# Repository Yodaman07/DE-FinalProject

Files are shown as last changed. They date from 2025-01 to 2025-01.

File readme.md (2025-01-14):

# Digital Electronics Final Project
### 3D Space Controller

## What does it do

The 3D Space Controller is a device that allows for traversal in 3D environments. You plug it into your computer and turn it on, and through hand gestures the device should allow for the rotation of a 3D landscape (currently only working in Blender) 

## How does it work

Pi: As you move your hand, the camera picks up what is happening and the pi (using mediapipe) processes the coordinates of your pointer finger, and puts it into `pi/data.json`. On a different thread, the pi is connected to the same wifi network as the arduino which enables it to send the data from that file to your "thing" on arduino cloud.

Arduino: The arduino then picks up that data and will move your mouse to those locations on your computer. **NOTE** It is essential to use an HID enabled arduino

## BOM

For the version of the device that I built, here were the materials that I used:

- Microsoft-Life-Cam-3000
- Raspberry Pi 4b
- Raspberry Pi Power supply
- Raspberry Pi 4b Case
- Arduino Nano ESP32
- USB-C to USB-C cable
- Front and Back plates printed in PLA (CAD located in `CAD/`) 
- Duct Tape and Foam from the box of the Arduino (The CAD had some issues which meant I had to be creative with fitting everything together)

## How to use yourself

On the pi inside of a venv (set up with `python -m venv env`, enter with `source env/bin/activate`, and leave with `deactivate`):

- Run `pip install -r requirements.txt` to install the necessary requirements
- Add a `.env` file to the `pi/` directory filled with your Arduino `DEVICE_ID` and `SECRET_KEY`
- Run `main.py`

Arduino Setup:

## Known Issues

It lags really badly - and the camera I'm using does not react well to really bright light

The CAD is kind of broken (things don't fit without some creative solutions) and doesn't needs to be adjusted more closely. The CAD models I ended up using were my prototype files that I printed once. 

## Cut Content (may be added in future versions)

Changing keystroke settings with an lcd
- I started to write code for it in `testing/lcd_controller` but didn't have time to implement it
- Additionally, I wanted to add a functionality with a joystick for manual control but I never got to experimenting with it

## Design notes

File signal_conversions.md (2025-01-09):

### Signal Conversions

After parsing the hand movements the raspberry pi needs to send them to the arduino before it can be sent to the computer. In doing this, the pi will send numbers associated with various keys and mouse commands that will be parsed/interpreted by the arduino then executed on your machine. Here are the key codes.

| Value (String) | Command |
|---|---|
| 10 | middleMouseDown |
| 11 | middleMouseUp |
| 20 | leftMouseDown |
| 21 | leftMouseUp |
| 30 | rightMouseDown |
| 31 | rightMouseUp |
| 123456788 | move_start |
| Numbers sent while movement is active | move(x,y) ; They are received as alternating x-y pairs |
| 123456789 | move_end |
| 404 | stop mouse control |

I should probably use a regex to read x/y coords, but I don't have too much time to implement it. I will probably come back and optimize this later.

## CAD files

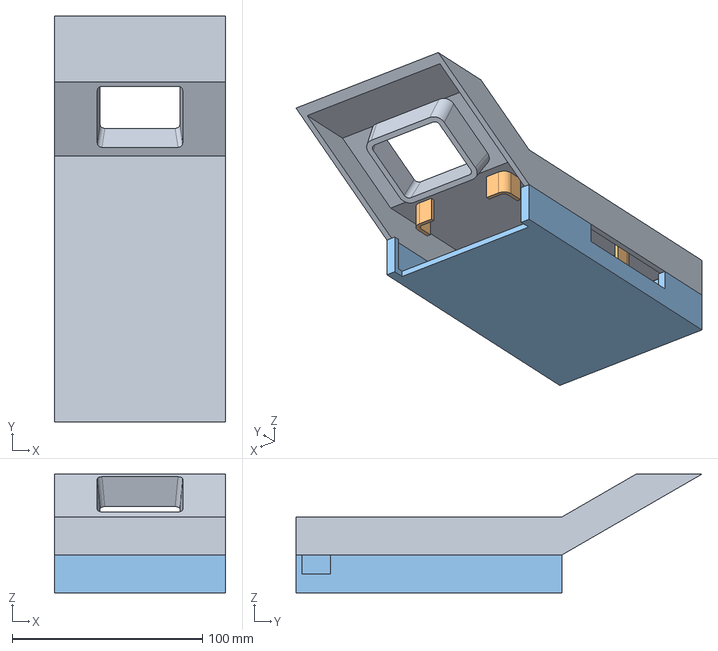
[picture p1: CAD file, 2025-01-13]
CAD/Case.step
90.0 x 213.6 x 62.5 mm
Front Plate
Back Plate

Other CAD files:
CAD/Case.f3z

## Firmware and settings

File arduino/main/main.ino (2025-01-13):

#include "thingProperties.h"
#include "USB.h"
#include "USBHIDMouse.h"



USBHIDMouse Mouse;


bool movementActive = false;
void setup() {
  // Initialize serial and wait for port to open:
  Serial.begin(9600);
  // This delay gives the chance to wait for a Serial Monitor without blocking if none is found
  delay(1500);

  // Defined in thingProperties.h
  initProperties();

  // Connect to Arduino IoT Cloud
  ArduinoCloud.begin(ArduinoIoTPreferredConnection);

  /*
     The following function allows you to obtain more information
     related to the state of network and IoT Cloud connection and errors
     the higher number the more granular information you’ll get.
     The default is 0 (only errors).
     Maximum is 4
 */
  setDebugMessageLevel(2);
  ArduinoCloud.printDebugInfo();

  USB.begin();
  Mouse.begin();
}

void loop() {
  ArduinoCloud.update();
  // Your code here

  // put your main code here, to run repeatedly:
  if ((mouseX != -1) && (mouseY !=-1) ){
      // Serial.print(mouseX);
      // Serial.print(" and ");
      // Serial.print(mouseY);
      // Serial.print(" ; ");
      // Serial.println(movementActive);
      Mouse.move(mouseX, mouseY);
      movementActive = true;
  }else{movementActive = false;}

  if (!movementActive){scanForOpperations(mouseState);} //Listening for other mouse signals if movement isn't active

}

void scanForOpperations(int data){
  switch (data){
      case 10:
        Mouse.press(MOUSE_MIDDLE);
        break;
      case 11:
        Mouse.release(MOUSE_MIDDLE);
        break;
      case 20:
        Mouse.press(MOUSE_LEFT);
        break;
      case 21:
        Mouse.release(MOUSE_LEFT);
        break;
      case 30:
        Mouse.press(MOUSE_RIGHT);
        break;
      case 31:
        Mouse.release(MOUSE_RIGHT);
        break;
      case 404:
        Mouse.end();
        break;
    }
}

/*
  Since MouseX is READ_WRITE variable, onMouseXChange() is
  executed every time a new value is received from IoT Cloud.
*/
void onMouseXChange()  {
  // Add your code here to act upon MouseX change
}


/*
  Since MouseY is READ_WRITE variable, onMouseYChange() is
  executed every time a new value is received from IoT Cloud.
*/
void onMouseYChange()  {
  // Add your code here to act upon MouseY change
}

/*
  Since MouseState is READ_WRITE variable, onMouseStateChange() is
  executed every time a new value is received from IoT Cloud.
*/
void onMouseStateChange()  {
  // Add your code here to act upon MouseState change
}

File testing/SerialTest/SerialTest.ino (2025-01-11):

#include "USB.h"
#include "USBHIDKeyboard.h"
USBHIDKeyboard Keyboard;

void setup() {
  // put your setup code here, to run once:
  Serial.begin(9600);
  // Keyboard.begin();
  // USB.begin();
  pinMode(LED_GREEN, OUTPUT);
}

void loop() {
  digitalWrite(LED_GREEN, LOW);
  // put your main code here, to run repeatedly:


  String data = "";
  if (Serial.available() > 0){
      data = Serial.readString();
  }

  if (data != ""){
    // Keyboard.print(data);
    digitalWrite(LED_GREEN, HIGH);
    delay(5000);
  }
}

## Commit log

2024-12-16 Worked on rotation and temporarily disabled the camera as rendering is really laggy
2024-12-23 Got rotation on the x-axis to workgit statusgit status
2025-01-09 completed arduino file. ready to test serial connections
2025-01-11 got some stuff with arduino cloud to workgit statusgit status
2025-01-12 Added multithreading and code updates if hand is detected - tomorrow ill work on the data transfer part/CAD
2025-01-13 Got mouse movement working with arduino cloud
2025-01-13 updated arduino code and analyzer now calculates difference
2025-01-13 added CAD files
    [Case.f3z, Case.step]
